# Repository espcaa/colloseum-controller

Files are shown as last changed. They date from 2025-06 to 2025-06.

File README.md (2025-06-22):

# The Colloseum-controller

What's colloseum? Simply the greatest smash-like tournament game ever, happening @highway (https://highway.hackclub.com), a hardware hackathon at github hq

## Wow look at it!!!!




## What is that, how does it works???

Based of an CH552G it can act as a usb keyboard so that your pc recognize it as a keyboard without any specific driver!
It uses quite a few techniques to bring down cost, everything is tht, the usb port is just a trace on the pcb, making it around 2-4$/board (hopefully)

## BOM

(prices for 1 unit, at 50 costs will go -50% thanks to lcsc)

| Name | Units | Price | LCSC Number
|---|-----|---|---|
| CH552G | 1  | 0.5575 | C111292 |
| 3mm led (any color) | 4 | 0.0228 | C2895458 |
| Resistors | 5 | 0.5 | NA |
| Button | 2 | 0.0466 | C22459507 |
| Joystick | 1 | 0.40 | C37323739 |
| PCB | 1 | 4.4 | NA |
| M3 Nut | 4 | 0.01 | C133377 |
| M3 Screw | 4 | .. | NA |

You also need some pla/petg/whatever to 3d print the case
The pcb can seem expensive but that's just the ENIG setup fee, we're at less than a dollar per pcb when ordering 50

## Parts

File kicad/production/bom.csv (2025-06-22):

Designator | Footprint | Quantity | Value | LCSC Part #
LED1, LED2, LED3, LED4 | LED-TH_BD4.0-P2.54-FD | 4 | 204-10SUBC/S400-A4 | C86881
R1 | JOYTICK-TH_YF16-DFL7.2-B5KO-45-10-B5KO-55--RG-A22 | 1 | YF16-FL7.2-B5KA(45-10)-R-A28 | C37323739
R2, R3, R4 | R_Axial_DIN0207_L6.3mm_D2.5mm_P7.62mm_Horizontal | 3 | 10
R5, R6 | R_Axial_DIN0207_L6.3mm_D2.5mm_P7.62mm_Horizontal | 2 | 5.1k
U1 | SOP-16_L10.0-W3.9-P1.27-LS6.0-BL | 1 | CH552G | C111292
U3, U4 | DIP6-DPDT | 2 | ~
U5 | USB_TYPE_C_W_2.0_5 | 1 | ~

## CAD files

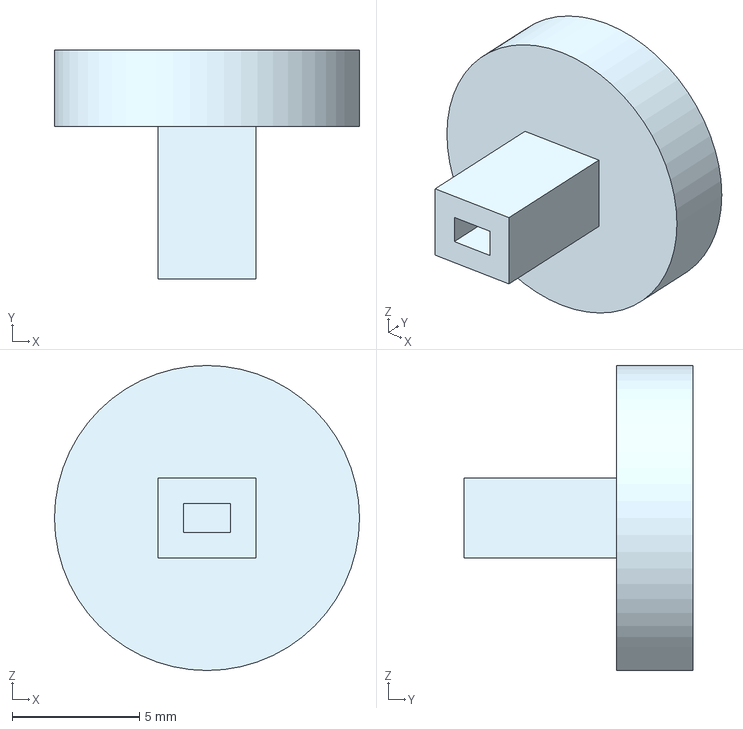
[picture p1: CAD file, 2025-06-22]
onshape/Part Studio 1 - Part 509.step
12.0 x 9.00 x 12.0 mm

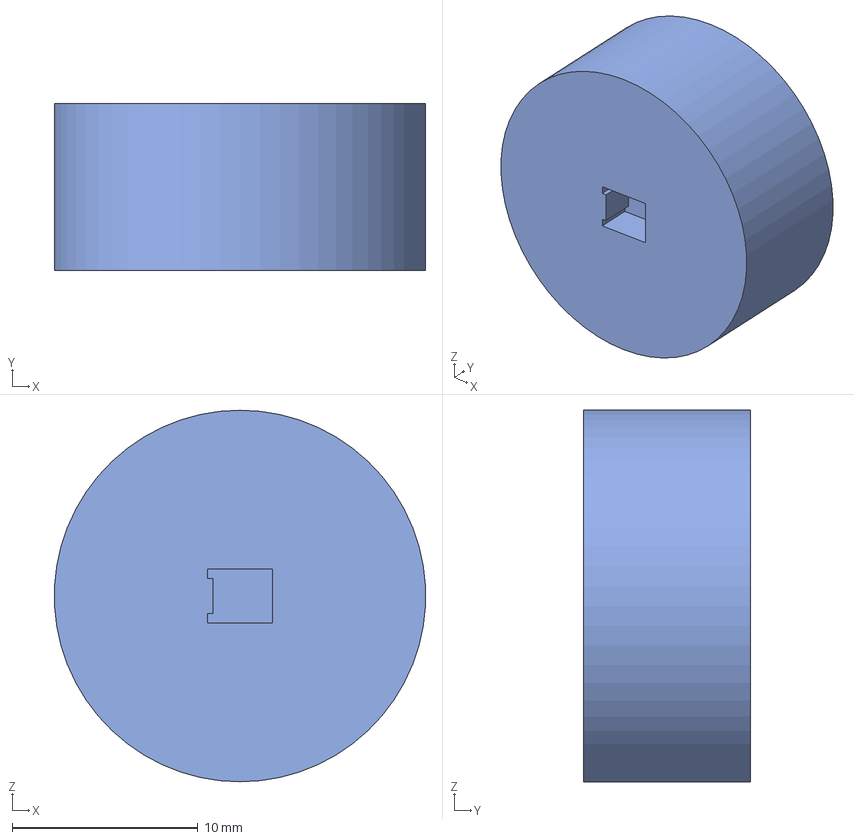
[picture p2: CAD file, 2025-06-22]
onshape/Part Studio 1 - Part 507.step
20.0 x 9.00 x 20.0 mm

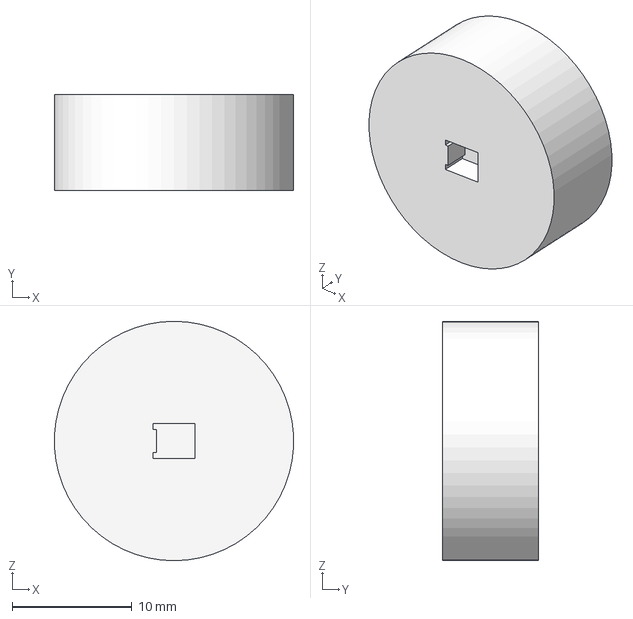
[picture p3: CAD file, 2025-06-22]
onshape/Part Studio 1 - Part 508.step
20.0 x 8.00 x 20.0 mm

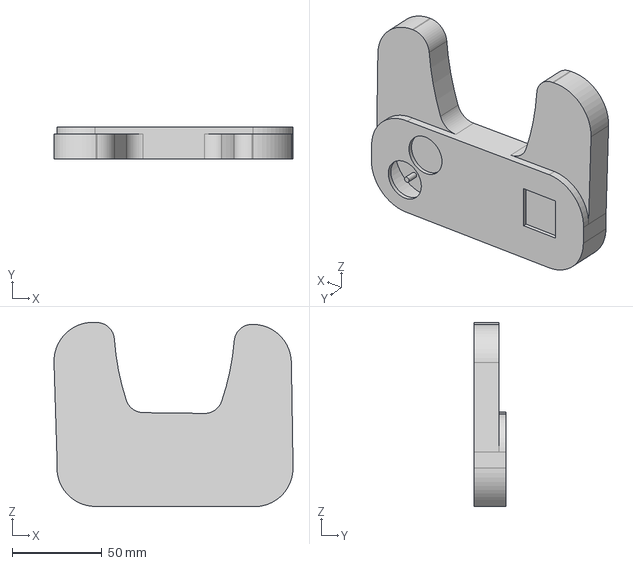
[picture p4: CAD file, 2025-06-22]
onshape/Part Studio 1 - Part 506.step
133.4 x 18.0 x 102.8 mm

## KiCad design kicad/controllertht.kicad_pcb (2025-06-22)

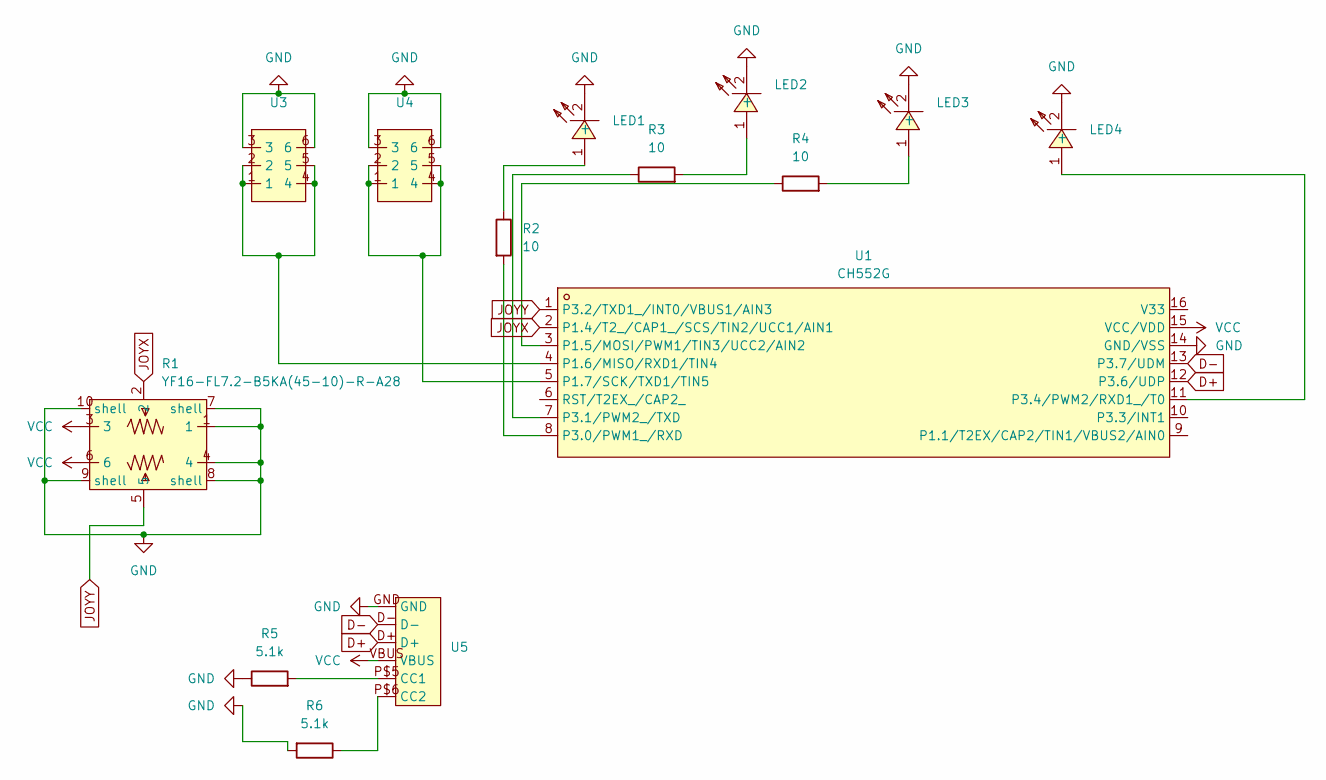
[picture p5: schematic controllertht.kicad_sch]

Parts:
LED1, LED2, LED3, LED4: 204-10SUBC/S400-A4; LED-TH_BD4.0-P2.54-FD; LCSC Part C86881
R1: YF16-FL7.2-B5KA(45-10)-R-A28; JOYTICK-TH_YF16-DFL7.2-B5KO-45-10-B5KO-55--RG-A22; LCSC Part C37323739
R2, R3, R4: 10; R_Axial_DIN0207_L6.3mm_D2.5mm_P7.62mm_Horizontal
R5, R6: 5.1k; R_Axial_DIN0207_L6.3mm_D2.5mm_P7.62mm_Horizontal
U1: CH552G; SOP-16_L10.0-W3.9-P1.27-LS6.0-BL; LCSC Part C111292
U3, U4: DIP6-DPDT
U5: USB_TYPE_C_W_2.0_5

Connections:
D+: U1.12 (P3.6/UDP), U5.D+
D-: U1.13 (P3.7/UDM), U5.D-
GND: LED1.2 (-), LED2.2 (-), LED3.2 (-), LED4.2 (-), R1.1, R1.4, R1.7 (shell), R1.8 (shell), R1.9 (shell), R1.10 (shell), R5.1, R6.2, U1.14 (GND/VSS), U3.3, U3.6, U4.3, U4.6, U5.GND
JOYX: R1.2, U1.2 (P1.4/T2_/CAP1_/SCS/TIN2/UCC1/AIN1)
JOYY: R1.5, U1.1 (P3.2/TXD1_/INT0/VBUS1/AIN3)
unnamed: LED1.1 (+), R2.1
unnamed: LED2.1 (+), R3.2
unnamed: LED3.1 (+), R4.2
unnamed: LED4.1 (+), U1.11 (P3.4/PWM2/RXD1_/T0)
unnamed: R4.1, U1.3 (P1.5/MOSI/PWM1/TIN3/UCC2/AIN2)
unnamed: U1.4 (P1.6/MISO/RXD1/TIN4), U3.1, U3.2, U3.4, U3.5
unnamed: U1.5 (P1.7/SCK/TXD1/TIN5), U4.1, U4.2, U4.4, U4.5
unnamed: R2.2, U1.8 (P3.0/PWM1_/RXD)
unnamed: R3.1, U1.7 (P3.1/PWM2_/TXD)
unnamed: R5.2, U5.P$5 (CC1)
unnamed: R6.1, U5.P$6 (CC2)
VCC: R1.3, R1.6, U1.15 (VCC/VDD), U5.VBUS

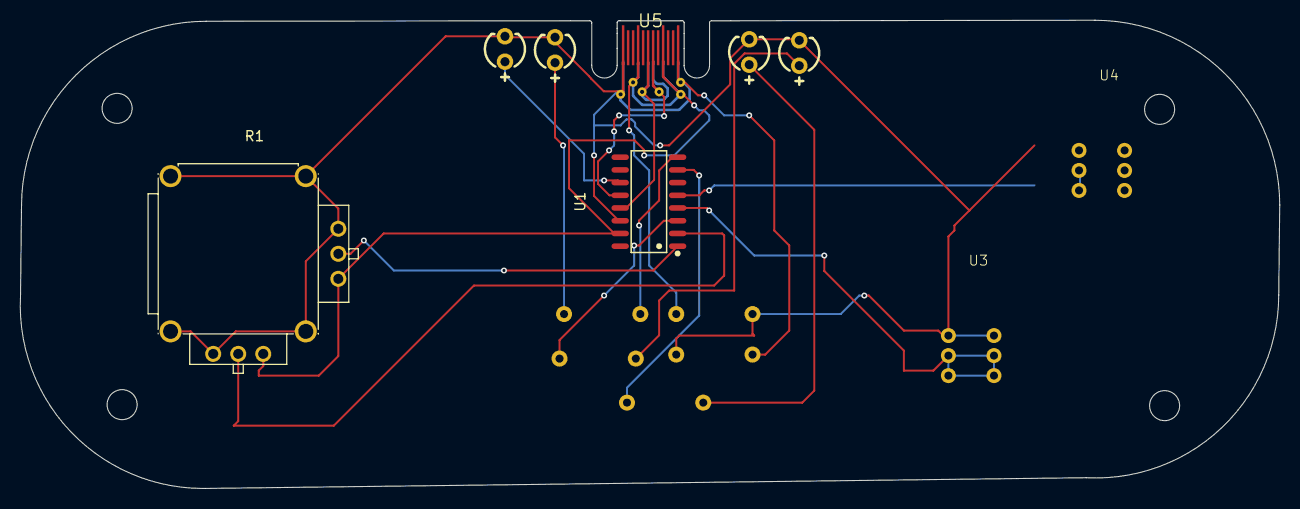
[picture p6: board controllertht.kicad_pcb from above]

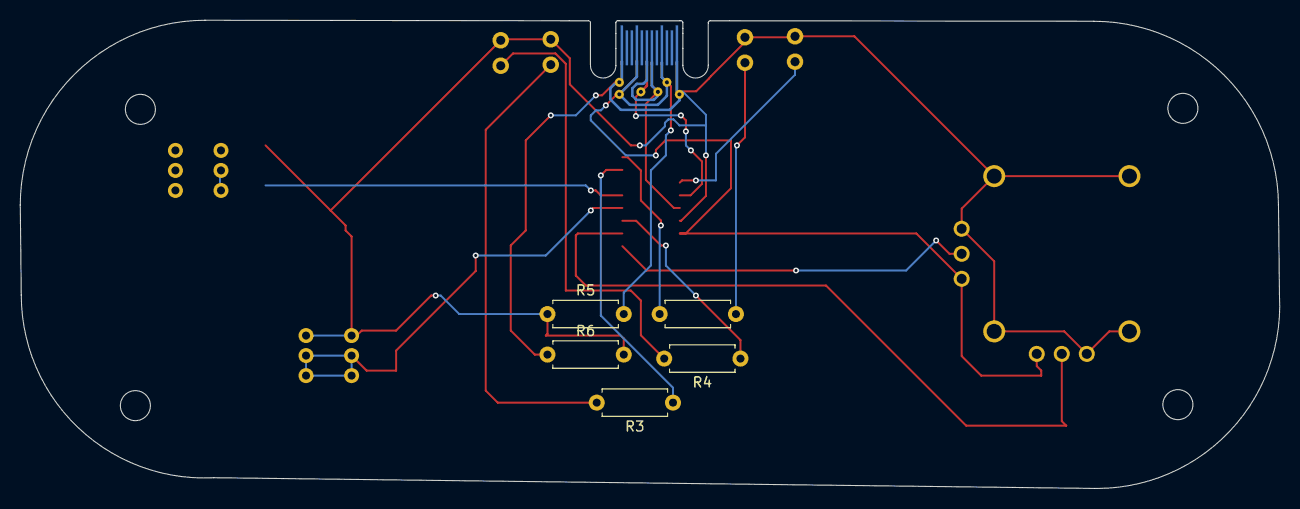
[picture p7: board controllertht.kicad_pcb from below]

Board: 2 copper layers, 125.8 x 46.8 mm, 14 parts (5 on the bottom side), 17 nets.

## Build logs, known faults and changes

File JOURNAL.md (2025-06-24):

---
title: "Colloseum controller"
author: "espcaa"
description: "A controller for undercity-colloseum, a smash-like tournament game at Highway"
created_at: "2025-06-22"
---

Total time spent: 11 hours

# The mysterious and very long (no) journal of the Colloseum controller

## Day 1 (of 2)

I started researching parts, finished the schematic!
I want this to be as cheap as possible so I went with a simple design and the cheapest component i could get on lcsc or simple to source leds/resistors with everything tht. I needed to find a good balance between shady and price :)
I ended up with a simple design with 4 buttons, 4 leds (Like the wii!!) and a usb port (usb-a at first then usb-c cause it's cooler) entirely made on the pcb to save even more costs (a usb port is 1.5$ on lcsc and very hard to solder yourself)
I spent a lot of time trying to understand the joystick schematic to wire it, the easyeda import wasn't very good :(



Time spent: approx 5 hours

## Day 2 (also of 2)

I finished the PCB wiring, started the case design and finished it! I don't exactly like it but i'll try to iterate over it later!
The pcb is at approx 3$/unit so that's really cool!
I spent a long time on the case (pcb wiring was also hard to do due to the tight space with the usb port) because I first wanted to make it looked good and I also had a lot of issues with importing my pcb from kicad to onshape :pf:. I finally managed to get it working by using assemblies, the right scale and the right import method (every piece in one file)
I tried multiple size before settling on one (not sure if it's the best one but it works for now) and tried to design something that would be somewhat easy to print and wouldn't look that bad while also being (a little bit) ergonomic.



Time spent: approx 6 hours

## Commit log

2025-06-22 added kicad+onshape files
    [Part Studio 1 - Part 506.step, Part Studio 1 - Part 507.step, Part Studio 1 - Part 508.step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]
2025-06-22 added bom
    [bom.csv]
2025-06-22 fixed the button
2025-06-22 changed the format
    [bom.csv]
2025-06-22 added m3 thingies
    [bom.csv]
